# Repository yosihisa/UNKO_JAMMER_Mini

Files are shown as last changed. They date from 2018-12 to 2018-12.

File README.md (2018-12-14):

# UNKO_JAMMER_Mini  
UNKO_JAMMER_Mini is a camera infrared　remote control. It can also handle washlets.  
It is compatible with Nikon, Canon, Sony and LIXIL.  
This repository is the source code of infrared remote control of the camera. (With washlette jack function)  
Video is [here](https://twitter.com/n_yosihisa/status/977338885901508608).  

# ウンコジャマー ミニとは
ウンコジャマーはカメラ用赤外線リモコンです。ウォシュレットを操作することもできます。  
Niko・Canon,Sonyの撮影コマンドとLIXILのおしりコマンドに対応しています。  
PENTAXは今後のアップデートで対応予定です。  
動画は[こちら](https://twitter.com/n_yosihisa/status/977338885901508608)です。

## 各部名称  
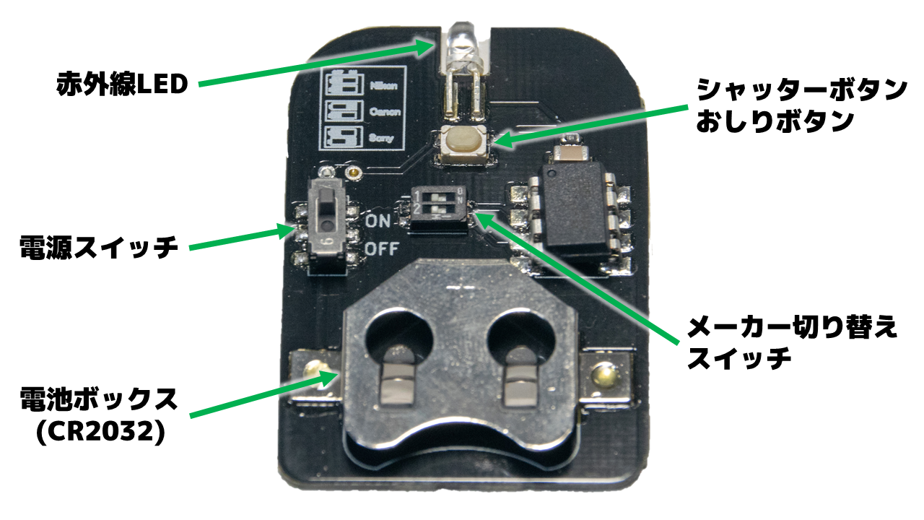
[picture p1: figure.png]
各部名称


## 使い方
### 準備 
コイン型リチウム電池(CR2032)を電池ボックスにセットします。  
電池の上にある黒いスイッチの白のつまみを利用するカメラのメーカーに合わせます。  

メーカー対応表  

|メーカー  |スイッチ1(上)  |スイッチ2(下)  |
|---|---|---|
|Nikon  |OFF(左)  |OFF(左)  |
|Canon  |ON (右)  |OFF(左)  |
|Sony |OFF (左) |ON (右)  |
|PENTAX |ON (右)  |ON (右)  |

### 撮影する
カメラをリモコン操作モードにします。(各機種の取扱説明書をご覧ください。)  
左側のスライドスイッチをONにします。  
LEDの下にある白いボタンを押すとシャッターを切ることができます。  
撮影が終了したら左側のスライドスイッチをoFFにしましょう。  

### おしりコマンドを発動する
おしりコマンドを発動するためには白いボタンを押しながら電源を入れる必要があります。  
白いボタンを押したまま電源を入れると、電源を切るまで白いボタンを押すたびにおしりコマンドが送信されます。

## 開発環境
- Atmel Studio 7
- KiCad 5.0.0
## 作者
よしひさ([@n_yosihisa](https://twitter.com/n_yosihisa))  
てぽ丼([@teppodone](https://twitter.com/teppodone))

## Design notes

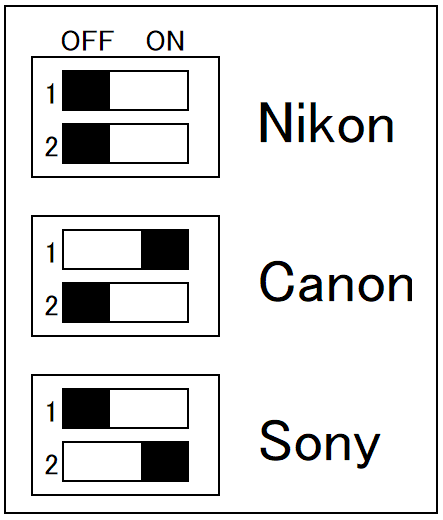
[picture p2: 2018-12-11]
PCB/mode.bmp

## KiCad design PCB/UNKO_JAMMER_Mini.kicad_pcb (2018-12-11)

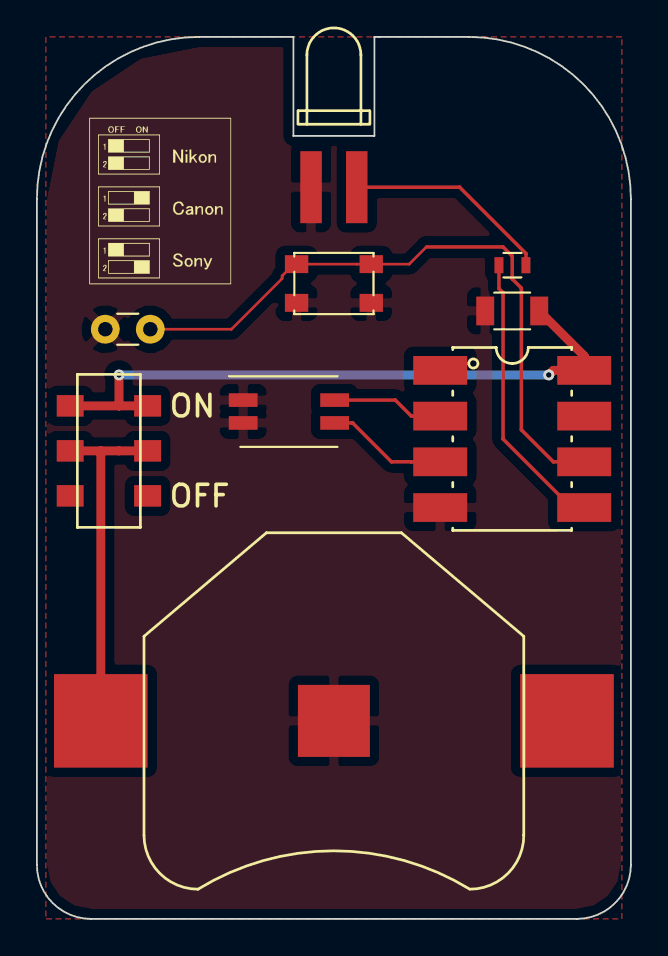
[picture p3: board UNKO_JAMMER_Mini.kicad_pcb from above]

Board: 2 copper layers, 33.0 x 49.0 mm, 9 parts (0 on the bottom side), 8 nets.

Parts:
BT1: C2032; BC-2001
C1: 100u; C_1206
D1: LED; 3mmLED
IC1: ATTINY10-P; DIP_SMD-8
J1: Remote; C_Disc_D3.0mm_W1.6mm_P2.50mm
R1: 100; R_0603
SW1: POWER; SSSS213202_parallel
SW2: RELEASE; SKRPACE010_kai
SW3: ModeSelector; SW_DIP_x2_W5.08mm_Slide_Copal_CHS-A

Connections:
/LED: IC1.5, R1.1
/ModeSelect0: IC1.3, SW3.3
/ModeSelect1: IC1.2, SW3.4
/Release: IC1.6, J1.2, SW2.2
GND: BT1.2, C1.2, D1.1, IC1.4, J1.1, SW2.1, SW3.1, SW3.2
unnamed: BT1.1, SW1.2
unnamed: C1.1, IC1.8, SW1.3
unnamed: D1.2, R1.2

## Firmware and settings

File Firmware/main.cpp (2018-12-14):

//Fuse Lo:0x0A Hi:0xFF
#define  F_CPU 1200000UL

#define USE_SLEEP 1 //1 スリープモードを有効にする 0 スリープモードを無効にする
#include <avr/io.h>
#include <util/delay.h>

#if USE_SLEEP == 1

#include <avr/interrupt.h>
#include <avr/sleep.h>

#define NIKON	0
#define CANON	1
#define SONY	2
#define PENTAX	3
#define LIXIL	4
int mode;

#endif

#define IR_ON()  (TCCR0A = 0b01000010)
#define IR_OFF() (TCCR0A = 0b00000010)
#define IR_ON_C()  (PORTB = 0b0000001)
#define IR_OFF_C() (PORTB = 0b0000010)

#define  c_mode		0b00011000
#define  c_nikon	0b00011000
#define  c_canon	0b00010000
#define  c_sony		0b00001000
#define  c_pentax	0b00000000

void IR_0(){
	IR_ON();	_delay_us(600);		IR_OFF();	_delay_us(600); //0
}
void IR_1(){
	IR_ON();	_delay_us(1200);	IR_OFF();	_delay_us(600); //1
}

void IR_0_nec(){
	IR_ON();	_delay_us(562);		IR_OFF();	_delay_us(562); //0
}
void IR_1_nec(){
	IR_ON();	_delay_us(562);	IR_OFF();	_delay_us(1686); //1
}

void IR_Canon_data(){
	for(int i=0;i<16;i++){
		IR_ON_C();	_delay_us(11);
		IR_OFF_C();	_delay_us(11);
	}
}

void PWM_int(){
	TCCR0A = 0b01000010;
	TCCR0B = 0b00000001;
	OCR0A = 14;
	IR_OFF();
}

void release_nikon(){
	IR_ON();	_delay_us(2000);
	IR_OFF();	_delay_us(28000);
	IR_ON();	_delay_us(200);
	IR_OFF();	_delay_us(1580);
	IR_ON();	_delay_us(400);
	IR_OFF();	_delay_us(3580);
	IR_ON();	_delay_us(400);
	IR_OFF();
	_delay_ms(100);
}
void release_canon(){
	IR_Canon_data();
	_delay_us(7330);
	IR_Canon_data();
	_delay_ms(100);
}
void release_sony(){
	
	IR_1();	IR_0();	IR_1();	IR_1();
	IR_0();	IR_1();	IR_0();	IR_0();
	IR_1();	IR_0();	IR_0();	IR_0();
	IR_1();	IR_1();	IR_1();	IR_1();
	
	_delay_ms(100);
}

void release_pentax(){
	IR_ON();	_delay_ms(13);
	IR_OFF();	_delay_ms(3);
	for(int i=0;i<7;i++){
		IR_ON();	_delay_us(1000);
		IR_OFF();	_delay_us(1000);	
	}
	_delay_ms(100);
	
}

void oshiri_lixil(){
	IR_ON();	_delay_us(8992);		IR_OFF();	_delay_us(4496); //0
	
	IR_0_nec();
	IR_1_nec();
	IR_0_nec();
	IR_1_nec();

	IR_1_nec();
	IR_1_nec();
	IR_0_nec();
	IR_0_nec();
	
	IR_1_nec();
	IR_0_nec();
	IR_0_nec();
	IR_0_nec();

	IR_1_nec();
	IR_1_nec();
	IR_0_nec();
	IR_1_nec();

	IR_0_nec();
	IR_1_nec();
	IR_1_nec();
	IR_1_nec();

	IR_0_nec();
	IR_0_nec();
	IR_1_nec();
	IR_0_nec();

	IR_0_nec();
	
	_delay_ms(100);
}

#if USE_SLEEP == 1
ISR(INT0_vect){
	cli();
	switch(mode){
		case NIKON:
			release_nikon();
			break;
		case CANON:
			release_canon();
			break;
		case SONY:
			release_sony();
			break;
		case PENTAX:
			release_pentax();
			break;
		case LIXIL:
			oshiri_lixil();
			break;
	}
	PORTB = 0b00000010;	
	sei();
}
#endif
int main(void)
{
	//入出力方向設定
	DDRB  = 0b00000001;
	PORTB = 0b00011010;

#if USE_SLEEP == 0 //スリープが無効	
	if((PINB & 0b00000010) == 0b00000000){
		PWM_int();
		 while (1) {
			 if((PINB & 0b00000010) == 0b00000000){
				 oshiri_lixil();
			 }
		 }
    }

	if((PINB & c_mode) == c_nikon){
		PWM_int();
		 while (1) {
			 if((PINB & 0b00000010) == 0b00000000){
				 release_nikon();
			 }
		 }
	}
	if((PINB & c_mode) == c_canon){
		 while (1) {
			 if((PINB & 0b00000010) == 0b00000000){
				 release_canon();
			 }
		 }
	}
	if((PINB & c_mode) == c_sony){
		PWM_int();
		 while (1) {
			 if((PINB & 0b00000010) == 0b00000000){
				 release_sony();
			 }
		 }
    }
	if((PINB & c_mode) == c_pentax){
		PWM_int();
		while (1) {
			if((PINB & 0b00000010) == 0b00000000){
				release_pentax();
			}
		}
	}

#else //スリープが有効
	if((PINB & 0b00000010) == 0b00000000){
		PWM_int();
		mode = LIXIL;
	}else{
		if((PINB & c_mode) == c_nikon){
			PWM_int();
			mode = NIKON;
		}
		if((PINB & c_mode) == c_canon){
			mode = CANON;
		}
		if((PINB & c_mode) == c_sony){
			PWM_int();
			mode = SONY;
		}
		if((PINB & c_mode) == c_pentax){
			PWM_int();
			mode = PENTAX;
		}
	}
	//スリープ設定
	MCUCR = 0b00101000;
	GIMSK = 0b01000000;
	set_sleep_mode(SLEEP_MODE_PWR_DOWN);
	sei();
	while (1)
	{
		IR_OFF();
		PORTB = 0b00000010;
		sleep_mode();
	}
#endif
}

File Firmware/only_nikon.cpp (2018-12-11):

#define  F_CPU 1200000UL
#include <avr/io.h>
#include <avr/interrupt.h>
#include <util/delay.h>
#include <avr/sleep.h>

#define IR_ON()  (TCCR0A = 0b01000010)
#define IR_OFF() (TCCR0A = 0b00000010)

ISR(INT0_vect){
	cli(); 
	IR_ON();	_delay_us(2000);
	IR_OFF();	_delay_us(28000);
	IR_ON();	_delay_us(200);
	IR_OFF();	_delay_us(1580);
	IR_ON();	_delay_us(400);
	IR_OFF();	_delay_us(3580);
	IR_ON();	_delay_us(400);
	IR_OFF();
	PORTB = 0b00000000;
	_delay_ms(50);
	sei();
}

int main(void)
{
	//入出力方向設定
	DDRB  = 0b00000001;
	PORTB = 0b00000000;
	
	//スリープ設定
	MCUCR = 0b00101000;
	GIMSK = 0b01000000;
	set_sleep_mode(SLEEP_MODE_PWR_DOWN);
	
	//38kHz発振設定
	TCCR0A = 0b01000010;
	TCCR0B = 0b00000001;
	OCR0A = 14;
	
    sei();
    while (1) 
    {
		IR_OFF();
		PORTB = 0b00000000;
		sleep_mode(); 
    }
}

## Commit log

2018-12-11 NT kyoto 2018 version
    [UNKO_JAMMER_Mini.kicad_pcb, UNKO_JAMMER_Mini.sch]
2018-12-14 PENTAXに対応 スリープモード追加
